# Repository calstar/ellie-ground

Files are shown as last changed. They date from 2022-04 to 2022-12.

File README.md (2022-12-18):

# ellie-ground
2022 Eillie Hot-fire Electronics Control

## Summary
**DAQboard.ino** file commands the ESP32 that reads data from sensors and commands from the COM Board, and sends data in a package to the COM Board.

**COMBoard.ino** file commands the ESP32 that receives data in a package from the DAQ  Board, sends commands to the DAQ Board, and sends data to MATLAB for plotting and data-saving purposes through the serial port.

**liveplot.m** is a MATLAB file that can receive data from the COM Board, create live plots, and save the data.
  1. **Change the test file name according to the trial number in the liveplot.m file.**
  2. Click "Run" to start the code, and close the plotting window to stop the code. Test data will be automatically stored in a spreadsheet under a folder called "**Test_Data_yyyy-mm-dd**."

## ESP32 MAC Addresses
- DAQ Breadboard:{0x24, 0x62, 0xAB, 0xD2, 0x85, 0xDC}
- COM Breadboard:{0xC4, 0xDD, 0x57, 0x9E, 0x91, 0x6C};
- DAQ Protoboard:

## ESP32 Pinouts (Updated 4/6)
-DAQ Breadboard:

## Software requirement
**Ctrl click (Windows) or Cmd click the following links to open them in new tabs**
1. Arduino (https://www.arduino.cc/en/software)
2. MATLAB (https://software.berkeley.edu/matlab®)
    - To control the serial port, you need to install the [**Instrument Control Toolbox**](https://www.mathworks.com/products/instrument.html).
3. (optional) An external code editing software such as Atom (https://atom.io) or Visual Studio (https://visualstudio.microsoft.com/downloads/).
    - Arduino IDE and MATLAB are sufficient for all the coding
4. (recommended) GitHub Desktop (https://desktop.github.com). You can pull, push, and edit files with ease. **Step 3 required if you would like to download GitHub Desktop as the software requires an external editor.**

## How to update
### Using Github Desktop
1. Make sure you have access to this project
    - Check with you administrators
2. Go to the Github app, sign in, and click on the top left corner. You should see a pop-up window with an "Add" button. Select that button and choose "Clone repository."
3. Search in "Filter you repositories" using the keyword "ellie-ground." Select the correct repository and click "Clone."
    - If you want this cloned repository to be in a different folder, change the "Local Path."
4. After you have edited and saved the file in the local repository, GitHub Desktop will detect changes and prompt you to commit. Make sure to double check your changes before committing.
5. On the bottom left corner, put down a short summary that describes what you have changed, then click "Commit to **main**."
6. In the middle of the screen (or on the top banner) you will see "Push commits to the origin remote." If you are sure that the commit is ready, click "Push origin."
6. Check the project online and see if the changes have been reflected.

### Using Git
Please refer to https://rocketry.gitbook.io/public/tutorials/avionics/git-and-workflow for more information.

## Helpful resources
### ESP32-DevkitC (for PCB application - antenna sticks out of board)
Getting started

https://docs.espressif.com/projects/esp-idf/en/latest/esp32/hw-reference/esp32/get-started-devkitc.html

Pinout reference

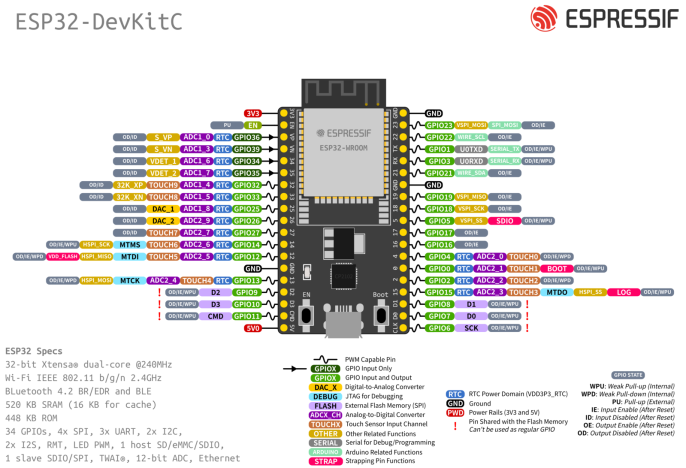
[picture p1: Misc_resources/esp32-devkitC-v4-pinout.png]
esp32 devkitC pinout ESP32 DevkitC Pinout


### ESP32-WROOM (for breadboard/protoboard application - antenna does NOT stick out of board)

Pinout reference
esp32 wroom pinout

### ESP32-HUZZAH (for breadboard/protoboard application)

Pinout reference
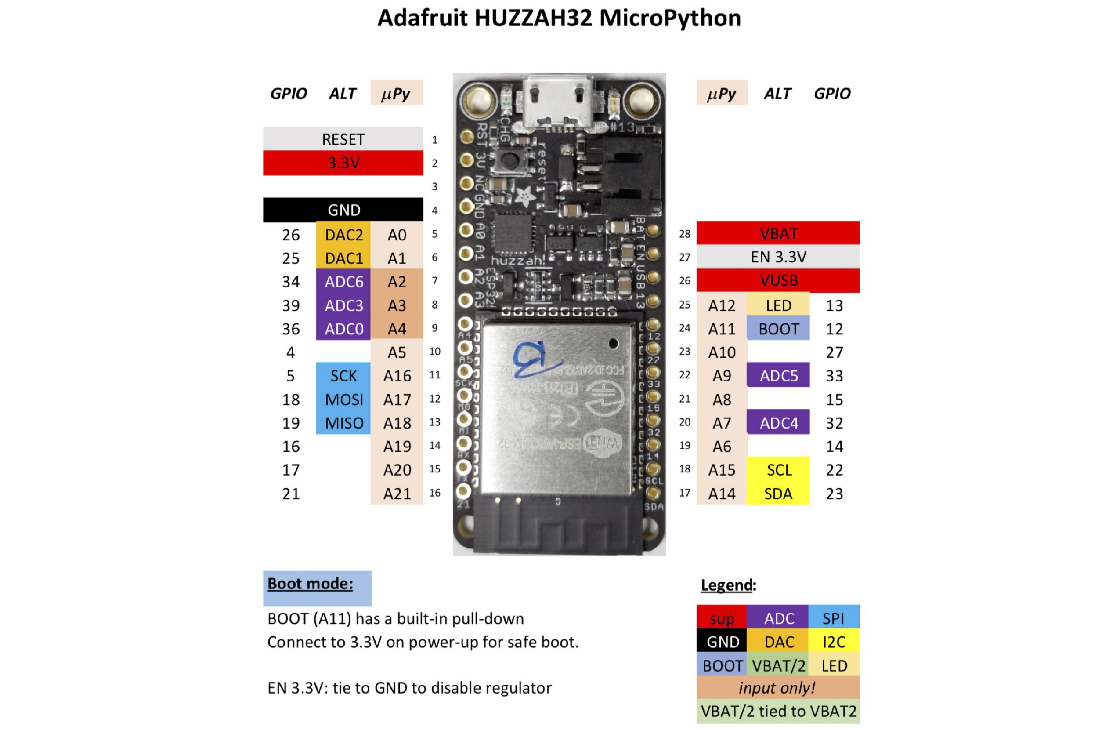
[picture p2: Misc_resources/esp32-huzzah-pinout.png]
esp32 devkitC pinout ESP32 HUZZAH Pinout


### Pressure transducer color code
Red - E+

Black - E-

Green - A-

White - A+

Other possible combinations: Blue E+; Red E-; Green A-; Black A+

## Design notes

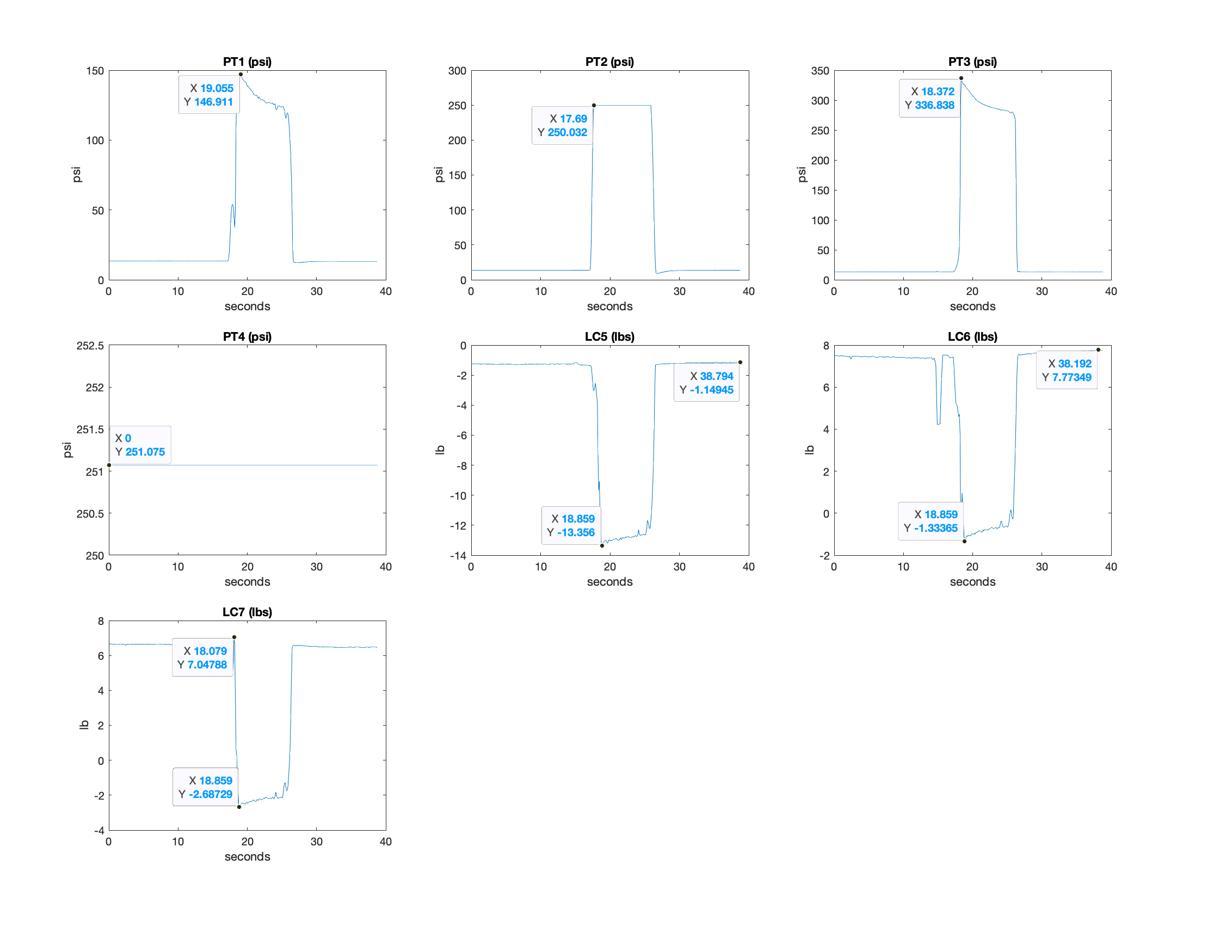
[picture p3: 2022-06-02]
DataAnalysis/Hotfire2DataTrimmedGraph.png

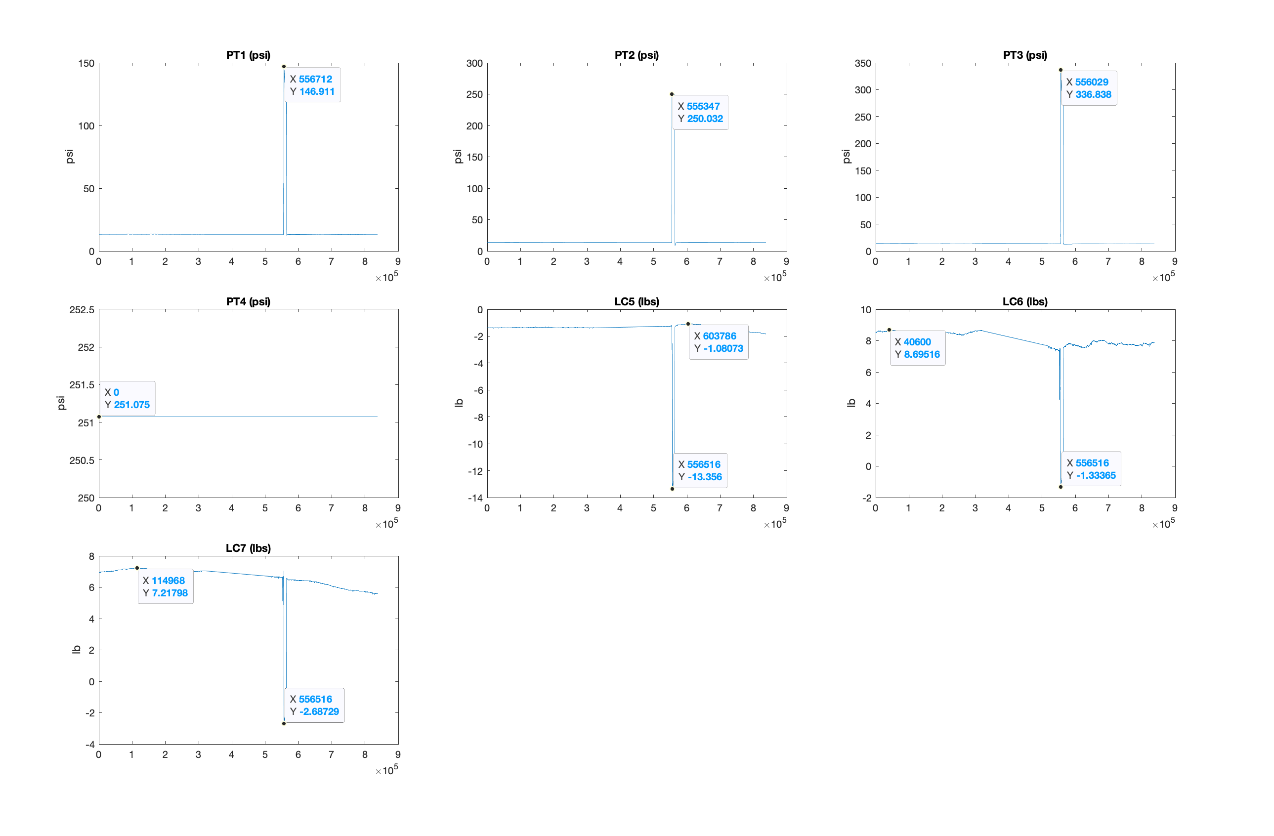
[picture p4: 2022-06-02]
DataAnalysis/Hotfire2DataProcessed.png

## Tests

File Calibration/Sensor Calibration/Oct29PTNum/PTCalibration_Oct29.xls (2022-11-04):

PT 1 | PT 2 | PT 3 | PT 4 | PT 5 | PT 6 | PT 7 | PT Readings
0.0009706526828 | 12.51203827 | 0.0009893543334 | 0.2012704162 | -133719235369059248 | -36146633045445000 | 69354593096977224
1.65048153 | -23513.65328 | 31.48686305 | 1559.537684 | -20057885305358816 | 30001705427719392 | -113741532679042560
8380.388889 | 1885.814815 | -22136.64815 | -7710.796296 | -0.15 | 0.83 | 1.64 | 14.7
55554.43046 | 1883.064982 | 24805.82 | -7349.636364 | -0.15 | 0.83 | 1.64 | 50
118709.5503 | 1885.245989 | 86323.95266 | -7282.704301 | -0.15 | 0.83 | 1.64 | 115
80205.55208 | 1884.510417 | 48400.64583 | -7229.824176 | -0.15 | 0.83 | 1.64 | 77
137342.2368 | 1889.48125 | 104446.4649 | -7198.40625 | -0.15 | 0.83 | 1.64 | 140

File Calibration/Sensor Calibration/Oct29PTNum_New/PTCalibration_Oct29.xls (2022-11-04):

PT 1 | PT 2 | PT 3 | PT 4 | PT 5 | PT 6 | PT 7 | PT Readings
0.0009157457122 | 0.03437664856 | 0.00104545149 | -0.007990707251 | 118398310289181120 | -17172367727786096 | 19827824667406704
7.487624458 | 14.54881995 | 26.42813521 | 19.595128 | 17759746543377252 | 14253065214062518 | -32517632454546908
8380.388889 | 1885.814815 | -22136.64815 | -7710.796296 | -0.15 | 0.83 | 1.64 | 14.7
55554.43046 | 1883.064982 | 24805.82 | -7349.636364 | -0.15 | 0.83 | 1.64 | 50
118709.5503 | 1885.245989 | 86323.95266 | -7282.704301 | -0.15 | 0.83 | 1.64 | 115
80205.55208 | 1884.510417 | 48400.64583 | -7229.824176 | -0.15 | 0.83 | 1.64 | 77
137342.2368 | 1889.48125 | 104446.4649 | -7198.40625 | -0.15 | 0.83 | 1.64 | 140
0 | 0 | -1 | 0 | -0.15 | 0.83 | 1.64 | 14.7

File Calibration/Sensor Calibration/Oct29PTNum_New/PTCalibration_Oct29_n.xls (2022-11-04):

PT 1 | PT 2 | PT 3 | PT 4 | PT 5 | PT 6 | PT 7 | PT Readings
0 | 0 | -153515758976703840 | 0 | 1.861742316e+15 | -3.535751283e+14 | -4.561532801e+14
19.85 | 19.85 | -153515758976703840 | 19.85 | 2.792613475e+14 | 2.934673565e+14 | 7.480913793e+14
0 | 0 | -1 | 0 | -0.15 | 0.83 | 1.64 | 14.7
0 | 0 | -1 | 0 | -0.15 | 0.83 | 1.64 | 25

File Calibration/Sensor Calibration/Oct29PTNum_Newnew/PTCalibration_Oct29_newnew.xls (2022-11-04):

PT 1 | PT 2 | PT 3 | PT 4 | PT 5 | PT 6 | PT 7 | PT Readings
0 | -234.3810036 | 0.1022941834 | 0 | -27526872320401832 | 4.169703457e+15 | 2.484431584e+15
111.51 | 105.7888889 | 28.23953968 | 111.51 | -4129030848060160 | -3460853869241820 | -4074467797335228
0 | 0 | 255 | 0 | -0.15 | 0.83 | 1.64 | -15.9
0 | 0 | 511 | 0 | -0.15 | 0.83 | 1.64 | 77
0 | 0 | 511 | 0 | -0.15 | 0.83 | 1.64 | 121
0 | -0.2440944882 | 1023 | 0 | -0.15 | 0.83 | 1.64 | 163
0 | 0 | 725.2927864 | 0 | -0.15 | 0.83 | 1.64 | 220
0 | 0 | 1023 | 0 | -0.15 | 0.83 | 1.64 | 195
0 | 0 | 1023 | 0 | -0.15 | 0.83 | 1.64 | 190
0 | 0 | 1023 | 0 | -0.15 | 0.83 | 1.64 | 63
0 | 0 | 1023 | 0 | -0.15 | 0.83 | 1.64 | 54
0 | 0 | 1023 | 0 | -0.15 | 0.83 | 1.64 | 48

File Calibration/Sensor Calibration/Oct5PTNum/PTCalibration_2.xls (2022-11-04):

PT 1 | PT 2 | PT 3 | PT 4 | PT 5 | PT 6 | PT 7 | PT Readings
0 | 9.928154529e-07 | 0 | 0 | -1.000799917e+15 | 1.087005989e+14 | -9.153657779e+13
14.7125 | 14.81074651 | 14.7125 | 14.7125 | -1.501199876e+14 | -9.022149707e+13 | 1.501199876e+14
0 | -99582.5 | 0 | 0 | -0.15 | 0.83 | 1.64 | 14.7
0 | -90180.9589 | 0 | 0 | -0.15 | 0.83 | 1.64 | 14.7
0 | -116377.3364 | 0 | 0 | -0.15 | 0.83 | 1.64 | 14.7
0 | -89689.1 | 0 | 0 | -0.15 | 0.83 | 1.64 | 14.75

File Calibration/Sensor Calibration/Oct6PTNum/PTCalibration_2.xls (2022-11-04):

PT 1 | PT 2 | PT 3 | PT 4 | PT 5 | PT 6 | PT 7 | PT Readings
0 | -7.311162168e-08 | 0 | 0 | 1.772839064e+14 | -2.232511728e+12 | -1.848005434e+13
14.70833333 | 14.70432553 | 14.70833333 | 14.70833333 | 2.659258596e+13 | 1.852984734e+12 | 3.030728911e+13
0 | -99582.5 | 0 | 0 | -0.15 | 0.83 | 1.64 | 14.7
0 | -90180.9589 | 0 | 0 | -0.15 | 0.83 | 1.64 | 14.7
0 | -116377.3364 | 0 | 0 | -0.15 | 0.83 | 1.64 | 14.7
0 | -89689.1 | 0 | 0 | -0.15 | 0.83 | 1.64 | 14.75
0 | 34295.94872 | 0 | 0 | -0.15 | 0.83 | 1.64 | 14.7
0 | 32628.66667 | 0 | 0 | -0.15 | 0.83 | 1.64 | 14.7

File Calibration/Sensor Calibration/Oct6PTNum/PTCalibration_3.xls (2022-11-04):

PT 1 | PT 2 | PT 3 | PT 4 | PT 5 | PT 6 | PT 7 | PT Readings
0 | 2.427443259e-05 | 18.31428571 | 0 | -308703343514374528 | -61703265420964744 | 50848568963502208
79.74444444 | 15.88315189 | 83.81428571 | 79.74444444 | -46305501527156112 | 51213710299400792 | -83391653100143536
0 | 26169.49153 | 0 | 0 | -0.15 | 0.83 | 1.64 | 14.7
0 | 946688.05 | 0 | 0 | -0.15 | 0.83 | 1.64 | 43
0 | 2184658.889 | -1 | 0 | -0.15 | 0.83 | 1.64 | 51
0 | 2312099.571 | 0 | 0 | -0.15 | 0.83 | 1.64 | 80
0 | 3136231.319 | 0 | 0 | -0.15 | 0.83 | 1.64 | 102
0 | 3182059.057 | 0 | 0 | -0.15 | 0.83 | 1.64 | 97
0 | 3586923.865 | 0 | 0 | -0.15 | 0.83 | 1.64 | 116
0 | 4287929.869 | 0 | 0 | -0.15 | 0.83 | 1.64 | 134

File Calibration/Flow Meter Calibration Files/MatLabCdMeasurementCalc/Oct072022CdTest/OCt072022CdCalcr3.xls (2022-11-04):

Time(ms) | PT 2 | PT 3 | PT 4 | volume flow (m^3/s) | break Interval | mass flow (kg/s) | Cd Value | Reynolds Num
114031 | 6894.76 | 101352.93 | 1 | 0 | 3000 | 0 | 0 | 0
117031 | 6894.76 | 101352.93 | 1 | 0 | 3000 | 0 | 0 | 0
120031 | 6894.76 | 101352.93 | 1 | 0 | 3000 | 0 | 0 | 0
123032 | 6894.76 | 101352.93 | 1 | 0 | 3001 | 0 | 0 | 0
126032 | 6894.76 | 101352.93 | 1 | 0 | 3000 | 0 | 0 | 0
128879 | 6894.76 | 101352.93 | 1 | 0 | 2847 | 0 | 0 | 0
128942 | 6894.76 | 101352.93 | 1 | 0 | 63 | 0 | 0 | 0
128980 | 6894.76 | 101352.93 | 1 | 0 | 38 | 0 | 0 | 0
129010 | 6894.76 | 101352.93 | 1 | 0 | 30 | 0 | 0 | 0
129035 | 6894.76 | 101352.93 | 1 | 0 | 25 | 0 | 0 | 0
129057 | 6894.76 | 101352.93 | 1 | 0 | 22 | 0 | 0 | 0
129077 | 6894.76 | 101352.93 | 1 | 0 | 20 | 0 | 0 | 0
129096 | 6894.76 | 101352.93 | 1 | 0 | 19 | 0 | 0 | 0
129114 | 6894.76 | 101352.93 | 1 | 0 | 18 | 0 | 0 | 0
129130 | 6894.76 | 101352.93 | 1 | 0 | 16 | 0 | 0 | 0
129146 | 6894.76 | 101352.93 | 1 | 0 | 16 | 0 | 0 | 0
129161 | 6894.76 | 101352.93 | 1 | 0 | 15 | 0 | 0 | 0
129175 | 6894.76 | 101352.93 | 1 | 0 | 14 | 0 | 0 | 0
129189 | 6894.76 | 101352.93 | 1 | 0 | 14 | 0 | 0 | 0
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

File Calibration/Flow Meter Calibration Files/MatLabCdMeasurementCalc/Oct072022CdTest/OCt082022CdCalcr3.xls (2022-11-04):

Time(ms) | PT 2 | PT 3 | PT 4 | volume flow (m^3/s) | break Interval | mass flow (kg/s) | Cd Value | Reynolds Num
36027 | 6894.76 | 101352.93 | 1 | 0 | 3001 | 0 | 0 | 0
39027 | 6894.76 | 101352.93 | 1 | 0 | 3000 | 0 | 0 | 0
42027 | 6894.76 | 101352.93 | 1 | 0 | 3000 | 0 | 0 | 0
44575 | 6894.76 | 101352.93 | 1 | 0 | 2548 | 0 | 0 | 0
44668 | 6894.76 | 101352.93 | 1 | 0 | 93 | 0 | 0 | 0
44719 | 6894.76 | 101352.93 | 1 | 0 | 51 | 0 | 0 | 0
44758 | 6894.76 | 101352.93 | 1 | 0 | 39 | 0 | 0 | 0
44791 | 6894.76 | 101352.93 | 1 | 0 | 33 | 0 | 0 | 0
44821 | 6894.76 | 101352.93 | 1 | 0 | 30 | 0 | 0 | 0
44847 | 6894.76 | 101352.93 | 1 | 0 | 26 | 0 | 0 | 0
44872 | 6894.76 | 101352.93 | 1 | 0 | 25 | 0 | 0 | 0
44896 | 6894.76 | 101352.93 | 1 | 0 | 24 | 0 | 0 | 0
44919 | 6894.76 | 101352.93 | 1 | 0 | 23 | 0 | 0 | 0
44941 | 6894.76 | 101352.93 | 1 | 0 | 22 | 0 | 0 | 0
44962 | 6894.76 | 101352.93 | 1 | 0 | 21 | 0 | 0 | 0
44983 | 6894.76 | 101352.93 | 1 | 0 | 21 | 0 | 0 | 0
45004 | 6894.76 | 101352.93 | 1 | 0 | 21 | 0 | 0 | 0
45024 | 6894.76 | 101352.93 | 1 | 0 | 20 | 0 | 0 | 0
45045 | 6894.76 | 101352.93 | 1 | 0 | 21 | 0 | 0 | 0
45065 | 6894.76 | 101352.93 | 1 | 0 | 20 | 0 | 0 | 0
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

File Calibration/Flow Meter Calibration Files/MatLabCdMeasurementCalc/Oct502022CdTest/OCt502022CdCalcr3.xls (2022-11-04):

Time(ms) | PT 2 | PT 3 | PT 4 | volume flow (m^3/s) | break Interval | mass flow (kg/s) | Cd Value | Reynolds Num
349916 | 137895.15 | 101352.93 | 0 | 0.0001133076307 | 96 | 0.000143900691 | 0.02778431128 | 5.316038151e-09
350004 | 137895.15 | 101352.93 | 0 | 0.0001122371665 | 88 | 0.0001425412014 | 0.02752182135 | 5.26581533e-09
350088 | 137895.15 | 101352.93 | 0 | 0.0001259108324 | 84 | 0.0001599067572 | 0.03087475873 | 5.90734079e-09
350179 | 137895.15 | 101352.93 | 0 | 0.000135928762 | 91 | 0.0001726295277 | 0.03333126825 | 6.37735058e-09
350272 | 137895.15 | 101352.93 | 0 | 0.0001290414354 | 93 | 0.000163882623 | 0.03164241796 | 6.054218849e-09
350365 | 137895.15 | 101352.93 | 0 | 9.777580043e-05 | 93 | 0.0001241752665 | 0.023975731 | 4.587333456e-09
350550 | 137895.15 | 101352.93 | 0 | 3.924362327e-05 | 185 | 4.983940155e-05 | 0.009622979823 | 1.841187545e-09
352600 | 137895.15 | 101352.93 | 0 | 0 | 2050 | 0 | 0 | 0

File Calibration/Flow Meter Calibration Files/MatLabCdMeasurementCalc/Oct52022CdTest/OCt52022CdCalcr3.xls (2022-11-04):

Time(ms) | PT 2 | PT 3 | PT 4 | volume flow (m^3/s) | break Interval | mass flow (kg/s) | Cd Value | Reynolds Num
616385 | 137895.15 | 101352.93 | 0 | 4.386883671e-05 | 394 | 5.571342263e-05 | 0.01075713442 | 2.058188033e-09
616461 | 137895.15 | 101352.93 | 0 | 0.0002053069637 | 76 | 0.0002607398439 | 0.05034358719 | 9.632357897e-09
616528 | 137895.15 | 101352.93 | 0 | 0.0003080311366 | 67 | 0.0003911995435 | 0.07553271502 | 1.445185345e-08
616616 | 137895.15 | 101352.93 | 0 | 0.0001200939701 | 88 | 0.000152519342 | 0.02944839837 | 5.634431879e-09
616725 | 137895.15 | 101352.93 | 0 | 8.486963714e-05 | 109 | 0.0001077844392 | 0.02081099394 | 3.981816811e-09
616860 | 137895.15 | 101352.93 | 0 | 5.033201708e-05 | 135 | 6.392166169e-05 | 0.01234197927 | 2.361420155e-09
617980 | 137895.15 | 101352.93 | 0 | 3.445683031e-05 | 1120 | 4.376017449e-05 | 0.008449204106 | 1.616606254e-09

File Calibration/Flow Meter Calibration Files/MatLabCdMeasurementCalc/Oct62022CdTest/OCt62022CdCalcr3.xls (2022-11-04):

Time(ms) | PT 2 | PT 3 | PT 4 | volume flow (m^3/s) | break Interval | mass flow (kg/s) | Cd Value | Reynolds Num
517058 | 103421.36 | 101352.93 | 0 | 0 | 82008 | 0 | 0 | 0
520059 | 103421.36 | 101352.93 | 0 | 0 | 3001 | 0 | 0 | 0
523059 | 103421.36 | 101352.93 | 0 | 0 | 3000 | 0 | 0 | 0
526059 | 103421.36 | 101352.93 | 0 | 0 | 3000 | 0 | 0 | 0
529059 | 103421.36 | 101352.93 | 0 | 0 | 3000 | 0 | 0 | 0
529351 | 103421.36 | 101352.93 | 0 | 0 | 292 | 0 | 0 | 0
529422 | 103421.36 | 101352.93 | 0 | 0 | 71 | 0 | 0 | 0
529476 | 103421.36 | 101352.93 | 0 | 0 | 54 | 0 | 0 | 0
529543 | 103421.36 | 101352.93 | 0 | 0 | 67 | 0 | 0 | 0
529613 | 103421.36 | 101352.93 | 0 | 0 | 70 | 0 | 0 | 0
529675 | 103421.36 | 101352.93 | 0 | 0 | 62 | 0 | 0 | 0
529736 | 103421.36 | 101352.93 | 0 | 0 | 61 | 0 | 0 | 0
529798 | 103421.36 | 101352.93 | 0 | 0 | 62 | 0 | 0 | 0
529862 | 103421.36 | 101352.93 | 0 | 0 | 64 | 0 | 0 | 0
529928 | 103421.36 | 101352.93 | 0 | 0 | 66 | 0 | 0 | 0
529994 | 103421.36 | 101352.93 | 0 | 0 | 66 | 0 | 0 | 0
530065 | 103421.36 | 101352.93 | 0 | 0 | 71 | 0 | 0 | 0
530149 | 103421.36 | 101352.93 | 0 | 0 | 84 | 0 | 0 | 0
530271 | 103421.36 | 101352.93 | 0 | 0 | 122 | 0 | 0 | 0
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

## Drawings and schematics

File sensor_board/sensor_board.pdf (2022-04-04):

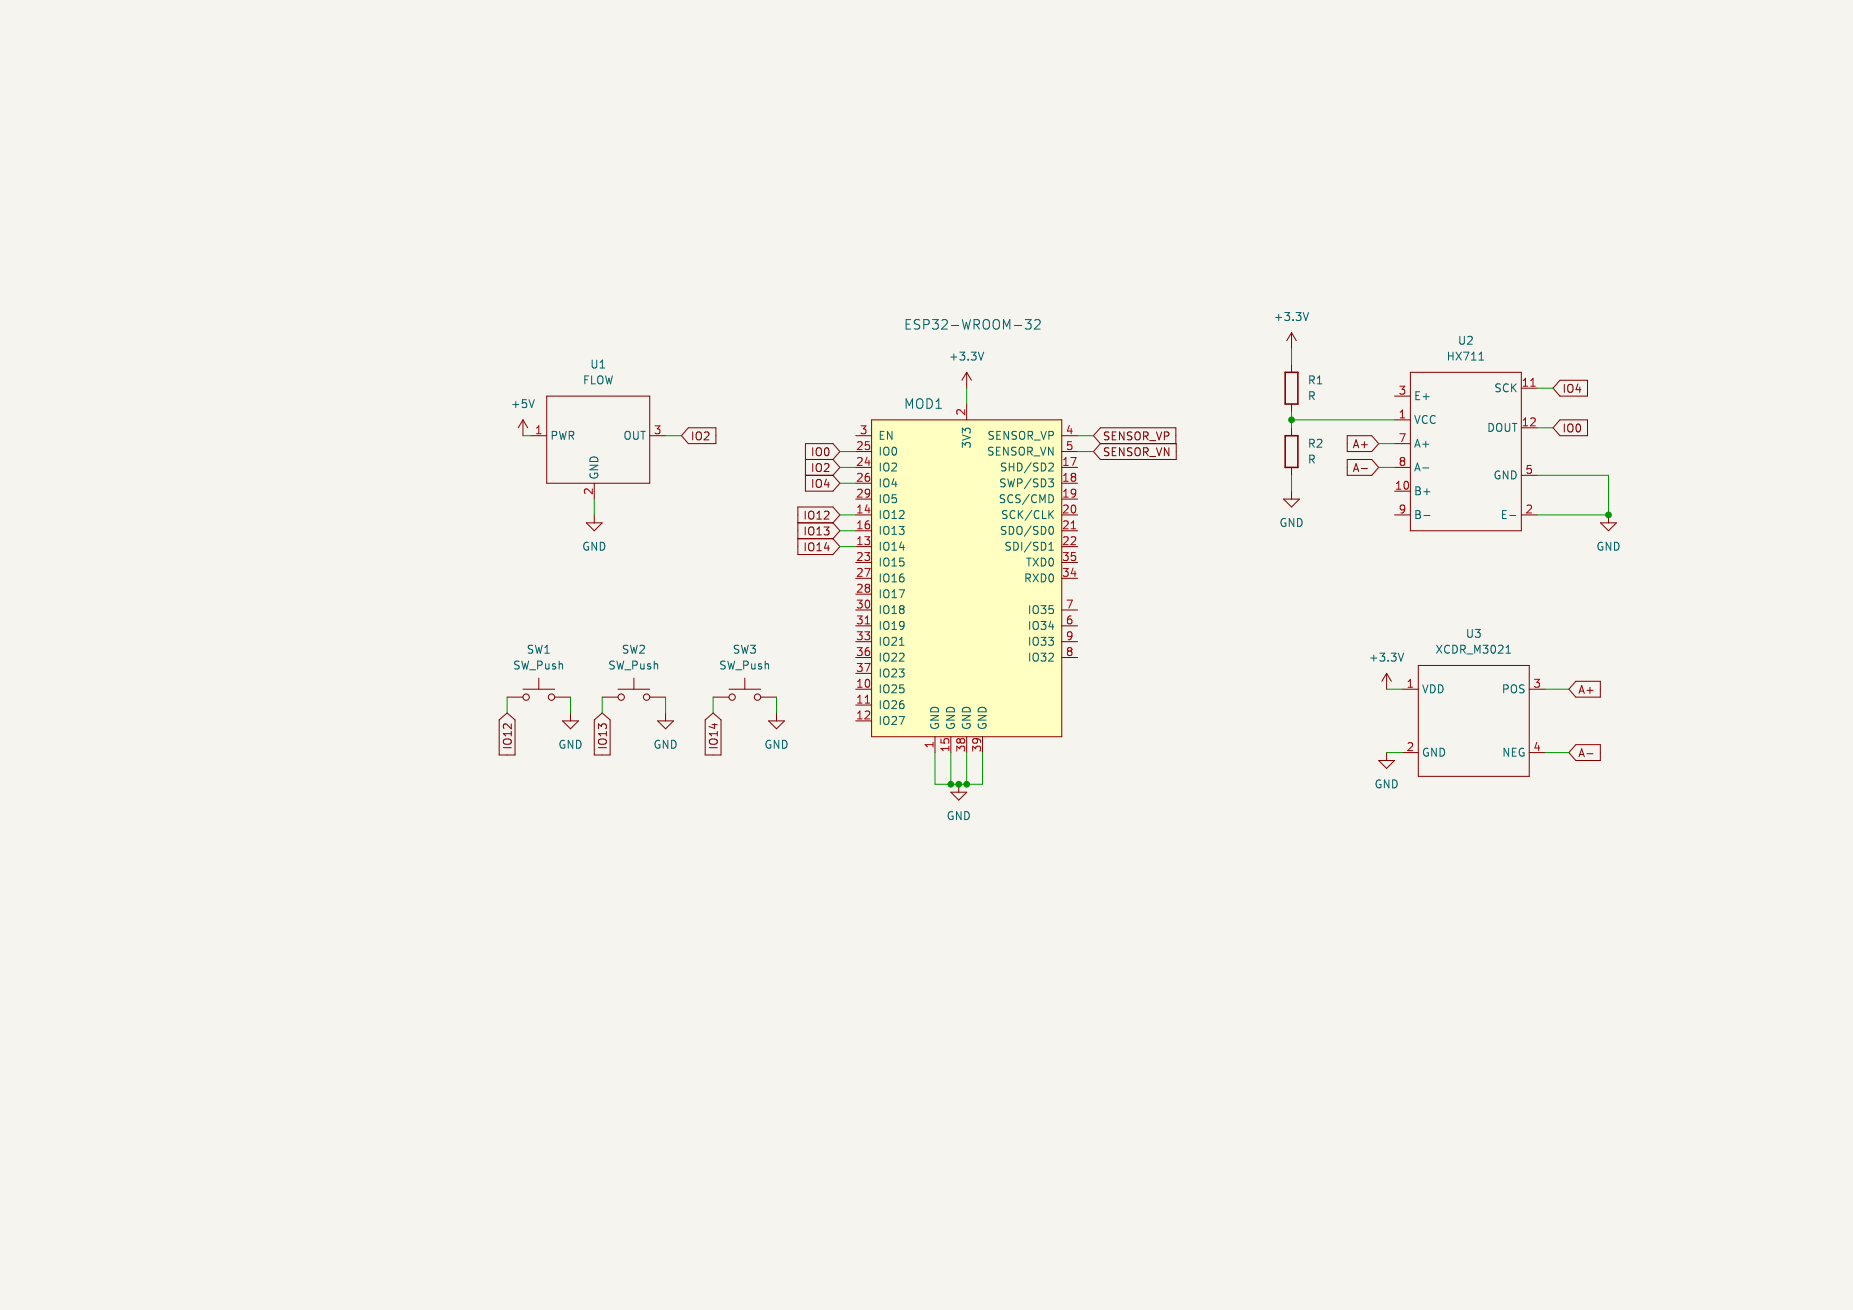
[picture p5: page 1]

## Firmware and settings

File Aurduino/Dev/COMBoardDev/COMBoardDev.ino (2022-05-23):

#include <esp_now.h>
#include <WiFi.h>
#include <ESP32Servo.h>
#include <Wire.h>
#include <Arduino.h>
#include "HX711.h"

#define BUTTON1 19
#define BUTTON2 17
#define BUTTON3 16
#define BUTTON4 21 //SET PIN NUMBER BUTTON

#define INDICATOR1  4 // state 2 light
#define INDICATOR2 23 // armed indicator
#define INDICATOR3 22//Servo1 indicator
#define INDICATOR4 14//seevo 2
#define INDICATOR5 25//daq indicaor
#define INDICATOR6 5//com indicator




#define servo1ClosedPosition 100
#define servo1OpenPosition 10
#define servo2ClosedPosition 80
#define servo2OpenPosition 160

float pressTime = 0;




String success;
String message;
int incomingMessageTime;
int servo1_curr = servo1ClosedPosition;
int servo2_curr = servo2ClosedPosition;
float incomingS1 = 0;
float incomingS2 = 0;
short int incomingPT1 = 4;
short int incomingPT2 = 4;
short int incomingPT3 = 4;
short int incomingPT4 = 4;
short int incomingFM = 0;
short int incomingLC1 = 0;
short int incomingLC2 = 0;
short int incomingLC3 = 0;
short int incomingI = 0;
int incomingDebug=0;
int actualState = -5;
short int queueSize=0;
esp_now_peer_info_t peerInfo;
bool pressed1 = false;
bool pressed2 = false;
bool pressed3 = false;
int commandstate = 0;


//TIMING VARIABLES
int state=-1;
int loopStartTime=0;
int ignitionSendDelay=50;
int pollingSendDelay=100;
int SendDelay=pollingSendDelay;

int commandedState;
int serialState;

int S1=servo1ClosedPosition;
int S2=servo2ClosedPosition;
int lastSendTime=0;

int lastPrintTime=0;
int PrintDelay =1000;



// SET FOR ACTIVE MODE //
bool hotfireMode = true;
//SET IF PLOTTING WITH MATLAB OR NOT. SERVO MANUAL CONTROL AND
//MATLAB PLOTTING ARE NOT COMPATIBLE DUE TO USING THE SAME SERIAL
//INPUT. IF TRUE, PLOTTING ENABLED. IF FALSE, MANUAL CONTROL ENABLED
bool MatlabPlot = true;


float button1Time = 0;
float currTime = 0;
float loopTime = 0;

float receiveTimeDAQ = 0;
float receiveTimeCOM = 0;

//for blinking LED during Data Collection
int x = 1;
unsigned long t1;
unsigned long t2;

//

//DAQ Breadboard {0x24, 0x62, 0xAB, 0xD2, 0x85, 0xDC}
//DAQ Protoboard {0x0C, 0xDC, 0x7E, 0xCB, 0x05, 0xC4}
//NON BUSTED DAQ {0x7C, 0x9E, 0xBD, 0xD8, 0xFC, 0x14}
// uint8_t broadcastAddress[] = {0x7C, 0x9E, 0xBD, 0xD8, 0xFC, 0x14}; //change to new Mac Address
// {0xC4, 0xDD, 0x57, 0x9E, 0x96, 0x34};

uint8_t broadcastAddress[] = {0x30, 0xC6, 0xF7, 0x2A, 0x28, 0x04};
//{0x30, 0xC6, 0xF7, 0x2A, 0x28, 0x04}

//Structure example to send data
//Must match the receiver structure
typedef struct struct_message {
    int messageTime;
    short int pt1;
    short int pt2;
    short int pt3;
    short int pt4;
    short int lc1;
    short int lc2;
    short int lc3;
    short int fm;
    unsigned char S1;
    unsigned char S2;
        int commandedState = 0;
        int DAQstate=0;

    unsigned char I;
    short int queueSize;
    int Debug;
} struct_message;

// Create a struct_message called Readings to recieve sensor readings remotely
struct_message incomingReadings;

// Create a struct_message to send commands
struct_message Commands;

//


void OnDataSent(const uint8_t *mac_addr, esp_now_send_status_t status) {
 // Serial.print("\r\nLast Packet Send Status:\t");
 // Serial.println(status == ESP_NOW_SEND_SUCCESS ? "Delivery Success" : "Delivery Fail");

  if (status == 0){
    success = "Delivery Success :)";
    digitalWrite(INDICATOR2, HIGH);
    receiveTimeDAQ = millis();
  }
  else{
    success = "Delivery Fail :(";
    digitalWrite(INDICATOR2, LOW);
  }
  // Serial.print(Commands.S1);
  // Serial.print(" ");
  // Serial.println(Commands.S2);

}

void OnDataRecv(const uint8_t * mac, const uint8_t *incomingData, int len) {
  memcpy(&incomingReadings, incomingData, sizeof(incomingReadings));
 // Serial.print("Bytes received: ");
   // Serial.println(len);
  incomingPT1 = incomingReadings.pt1;
     // Serial.print(incomingPT1);

     digitalWrite(INDICATOR1,HIGH);

  incomingMessageTime= incomingReadings.messageTime;
  incomingPT2 = incomingReadings.pt2;
  incomingPT3 = incomingReadings.pt3;
  incomingPT4 = incomingReadings.pt4;
  incomingFM = incomingReadings.fm;
  incomingLC1 = incomingReadings.lc1;
  incomingLC2 = incomingReadings.lc2;
  incomingLC3 = incomingReadings.lc3;
  incomingS1 = incomingReadings.S1;
  incomingS2 = incomingReadings.S2;
  queueSize= incomingReadings.queueSize;
  incomingI = incomingReadings.I;
  actualState = incomingReadings.DAQstate;
  incomingDebug= incomingReadings.Debug;


  receiveTimeCOM = millis();
  // Serial.println("Data received");
  RecieveDataPrint();

}

void SerialRead() {
    if (Serial.available() > 0) {
 serialState=Serial.read()-48;
 Serial.print("AVAILABLE--------------------");
   // Serial.println(serialState);
   // Serial.println(" ");

  }
     //   Serial.println(commandedState);
     //    Serial.println(" ");

}









void setup() {
  Serial.println("Start of Setup");
  Commands.S1 = servo1ClosedPosition;
  Commands.S2 = servo2ClosedPosition;
  // put your setup code here, to run once:
  Serial.begin(115200);
  pinMode(BUTTON1,INPUT);
  pinMode(BUTTON2, INPUT);
  pinMode(BUTTON3,INPUT);
  pinMode(BUTTON4, INPUT);

  pinMode(INDICATOR2, OUTPUT);
  pinMode(INDICATOR3, OUTPUT);
  pinMode(INDICATOR4, OUTPUT);
  pinMode(INDICATOR5, OUTPUT);
  pinMode(INDICATOR6, OUTPUT);
  pinMode(INDICATOR1, OUTPUT);

  digitalWrite(INDICATOR2,LOW);
  digitalWrite(INDICATOR3, LOW);
  digitalWrite(INDICATOR4, LOW);
  digitalWrite(INDICATOR5, LOW);
  digitalWrite(INDICATOR6, LOW);
  digitalWrite(INDICATOR1, LOW);


  //set device as WiFi station
  WiFi.mode(WIFI_STA);

  //initialize ESP32
   if (esp_now_init() != ESP_OK) {
  //  Serial.println("Error initializing ESP-NOW");
    return;
  }
   // Once ESPNow is successfully Init, we will register for Send CB to
  // get the status of Trasnmitted packet
  esp_now_register_send_cb(OnDataSent);

  // Register peer
  memcpy(peerInfo.peer_addr, broadcastAddress, 6);
  peerInfo.channel = 0;
  peerInfo.encrypt = false;

  // Add peer
  if (esp_now_add_peer(&peerInfo) != ESP_OK){
 //   Serial.println("Failed to add peer");
    return;
  }
  // Register for a callback function that will be called when data is received
  esp_now_register_recv_cb(OnDataRecv);

  //  Serial.println(WiFi.macAddress());


}



void printLine(String string) {
  Serial.println(string);
}


void LEDUpdate() {


if (incomingS1 == servo1OpenPosition) digitalWrite(INDICATOR3,HIGH); else digitalWrite(INDICATOR3,LOW);
if (incomingS2 == servo2OpenPosition) digitalWrite(INDICATOR4,HIGH); else digitalWrite(INDICATOR4,LOW);
digitalWrite(INDICATOR1,LOW);


}



void loop() {
loopStartTime=millis();
SerialRead();
// State selector
//Serial.println(actualState);

LEDUpdate();


switch (state) {

  case (17): //BASIC WIFI TEST DEBUG STATE A STATE
   wifiDebug();

    if (serialState==1) {state=1;}
  break;


  case (18): //COM INTERFACE BUTTON DEBUG STATE  B STATE
  comDebug();

    if (serialState==1) {state=1;}
  break;

  case (-1): //start single loop

  state=0;
  break;


  case (0): //Default/idle
      idle();


    state=1;
    break;

  case (1): //Polling
      polling();



      if ((digitalRead(BUTTON2)==1)||(serialState==2)) { state=3; S1=servo1ClosedPosition; S2=servo2ClosedPosition; SendDelay=pollingSendDelay; }
    if (serialState==18) {state=18;}
    if (serialState==17) {state=17;}

    break;

  case (2): //Manual Servo Control

 manualControl();


   if ((serialState==40)) { state=0; SendDelay=pollingSendDelay; }

    break;

  case (3): //Armed

armed();


    //button to ignition
      if ((digitalRead(BUTTON3)==1)||(serialState==3)) { state=4; S1=servo1ClosedPosition; S2=servo2ClosedPosition; SendDelay=ignitionSendDelay; }
      //RETURN BUTTON
      if ((digitalRead(BUTTON1)==1)||(serialState==1)) { state=1; S1=servo1ClosedPosition; S2=servo2ClosedPosition; SendDelay=pollingSendDelay; }

    break;


  case (4): //Ignition

    ignition();
    //HOTFIRE BUTTON
      if ((digitalRead(BUTTON4)==1)||(serialState==4)) state=5;
      //RETURN BUTTON
      if ((digitalRead(BUTTON1)==1)||(serialState==1)) { state=1; S1=servo1ClosedPosition; S2=servo2ClosedPosition; SendDelay=pollingSendDelay; }



    break;
  case (5): //Hotfire stage 1

    hotfire();

    if (actualState==0) state=0;


    break;

}

}
void statePrint() {


}



void idle() {
  dataSendCheck();
    digitalWrite(INDICATOR5,LOW);

}

void polling() {
  commandedState=1;
  dataSendCheck();
  digitalWrite(INDICATOR5,HIGH);

}

void manualControl() {
  commandedState=2;
  dataSendCheck();

    digitalWrite(INDICATOR5,LOW);


}

void armed() {
  commandedState=3;
  dataSendCheck();
  digitalWrite(INDICATOR5,LOW);

}

void ignition() {
  commandedState=4;
  dataSendCheck();

}

void hotfire() {
  commandedState=5;
  dataSendCheck();

}

void dataSendCheck() {
  if ((loopStartTime-lastSendTime) > SendDelay) dataSend();
}


void dataSend() {
   // Set values to send
  Commands.S1= S1;
  Commands.S2= S2;
  Commands.commandedState = commandedState;

  // Send message via ESP-NOW
  esp_err_t result = esp_now_send(broadcastAddress, (uint8_t *) &Commands, sizeof(Commands));

  if (result == ESP_OK) {
   //  Serial.println("Sent with success Data Send");
  }
  else {
  //   Serial.println("Error sending the data");
  }

  lastSendTime=loopStartTime;
}







void oldcode() {
  message = "";





  switch (state) {
    case 0:


      digitalWrite(INDICATOR2, LOW);
      digitalWrite(INDICATOR1, LOW);

      currTime = millis();
      if (pressed1 && ((currTime - button1Time) > 1000)) {
        state = 1;
        button1Time = currTime;
        // Serial.println("State 1");
        // Serial.println("BUTTON 1 GOOD");
      }

      break;

    case 1:


      pressed2 = digitalRead(BUTTON2);
      pressed3 = digitalRead(BUTTON1);
      currTime = millis();
      if (pressed2) {

        if (hotfire) state = 4; else state = 2;

        if (hotfire) {
          state = 4;
        } else {
          state = 2;
      }

        // Serial.println("State 2");
      }
      if (pressed3 && ((currTime - button1Time) > 1000)) {
        button1Time = currTime;
        state = 0;
        // Serial.println("State 0");
      }
      if ((millis() - receiveTimeDAQ) > 50) {
        digitalWrite(INDICATOR5, LOW);
      }
      if ((millis() - receiveTimeCOM) > 50) {
        digitalWrite(INDICATOR6, LOW);
      }
      break;
    case 2:
    //  Serial.println("State 2");
      //Serial.println("IN CASE 2");
      if (MatlabPlot) {
        Commands.S1 = 90 - servo1_curr;
        Commands.S2 = 90 - servo2_curr;
        servo1_curr = 90 - servo1_curr;
        servo2_curr = 90 - servo2_curr;
        pressTime = millis();
        digitalWrite(INDICATOR1, HIGH);

        while (millis() - pressTime <= 5000) {

          t2=millis();
          if (t2-t1 >=100){
              x=1-x;
              t1=millis();
              digitalWrite(INDICATOR2,x);
              // Serial.print(t1);
            }

          pressed3 = digitalRead(BUTTON1);
          if (pressed3) {
            state = 0;
            break;
          }
          if (state == 3) {
            break;
          }
          if ((millis() - receiveTimeDAQ) > 50) {
            digitalWrite(INDICATOR5, LOW);
          }
          if ((millis() - receiveTimeCOM) > 50) {
            digitalWrite(INDICATOR6, LOW);
          }

          if ((millis() - loopTime) >= 50) {
            esp_err_t result = esp_now_send(broadcastAddress, (uint8_t *) &Commands, sizeof(Commands));
            if (result != ESP_OK) {
              break;
            // Serial.println("Sent with success");
            }
            //else {
              //Serial.println("Error sending the data");



         }
        }

      } else {
        while (!Serial.available()) {
          pressed3 = digitalRead(BUTTON1);
          // Serial.print(pressed3);
          delay(5);
          if ((millis() - receiveTimeDAQ) > 50) {
            digitalWrite(INDICATOR5, LOW);
          }
          if ((millis() - receiveTimeCOM) > 50) {
            digitalWrite(INDICATOR6, LOW);
          }
          esp_err_t result = esp_now_send(broadcastAddress, (uint8_t *) &Commands, sizeof(Commands));
            if (result != ESP_OK) {
              break;
            // Serial.println("Sent with success");
            }
            //else {
              //Serial.println("Error sending the data");
            //}
          if (pressed3) {
            state = 0;
            // Serial.println("State 0");
            break;}  //waiting for inputs
          }
        String angles = Serial.readString();
        int index = angles.indexOf(",");
        String readAngle1 = angles.substring(0, index);
        String readAngle2 = angles.substring(index+1, angles.length());
        if (angles.length() >= 3) {
          Serial.println(readAngle1);
          Serial.println(readAngle2);
          Commands.S1 = readAngle1.toInt();
          Commands.S2 = readAngle2.toInt();
          if (Commands.S1 == servo1ClosedPosition) {
            digitalWrite(INDICATOR3, LOW);
          } else {
            digitalWrite(INDICATOR3, HIGH);
          }

          if (Commands.S2 == servo2ClosedPosition) {
            digitalWrite(INDICATOR4, LOW);
          } else {
            digitalWrite(INDICATOR4, HIGH);
          }
          esp_err_t result = esp_now_send(broadcastAddress, (uint8_t *) &Commands, sizeof(Commands));
          if (result != ESP_OK) {
              break;
            // Serial.println("Sent with success");
            }
            //else {
              //Serial.println("Error sending the data");
            //}

        }

      }
      break;
     case 3:
    //  Serial.println("State 3");
      Commands.S1 = servo1ClosedPosition;
      Commands.S2 = servo2ClosedPosition;
      digitalWrite(INDICATOR5, LOW);
      digitalWrite(INDICATOR6, LOW);
      digitalWrite(INDICATOR3, LOW);
      digitalWrite(INDICATOR4, LOW);
      if ((millis() - receiveTimeDAQ) > 50) {
        digitalWrite(INDICATOR5, LOW);
      }
      if ((millis() - receiveTimeCOM) > 50) {
        digitalWrite(INDICATOR6, LOW);
      }

      break;
    case 4:


      // Serial.println("State 4");
      if (incomingReadings.DAQstate == 4 || commandstate == 4){
        Commands.commandedState = 4;
        Serial.println("case 3 command state 3");


      } else {
          Commands.commandedState = 3;
          Serial.println("case 4 command state 3");
      }


      digitalWrite(INDICATOR1, HIGH);
      if (digitalRead(BUTTON1)) {
        state = 0;
        }
        if ((millis() - receiveTimeDAQ) > 100) {
          digitalWrite(INDICATOR5, LOW);
        }
      if ((millis() - receiveTimeCOM) > 100) {
        digitalWrite(INDICATOR6, LOW);
        }



      if (digitalRead(BUTTON1)) {
        state = 0;
      }
      if ((millis() - receiveTimeDAQ) > 100) {
        digitalWrite(INDICATOR5, LOW);
      }
      if ((millis() - receiveTimeCOM) > 100) {
        digitalWrite(INDICATOR6, LOW);
      }
      break;
    case 5:
    Serial.println(commandstate);
    if (incomingReadings.DAQstate == 5 || commandstate == 5) {
        Commands.commandedState = 5;

    } else  {
        Commands.commandedState = 4;
      }



      if (digitalRead(BUTTON4)) {
        Commands.commandedState = 5;
        commandstate = 5;
        Serial.print("yyyyyyy");

      if (digitalRead(BUTTON4)) {
        // Commands.I = true;
        Commands.S1 = servo1OpenPosition;
        Commands.S2 = servo2OpenPosition;
        // Serial.println(Commands.I);
        esp_err_t result = esp_now_send(broadcastAddress, (uint8_t *) &Commands, sizeof(Commands));

        if (result != ESP_OK) {

          break;
          }


        state = 0;

        float now = millis();
        float runningTime = millis();
        digitalWrite(INDICATOR3, HIGH);
        digitalWrite(INDICATOR4, HIGH);
        while ((now - runningTime) <= 3000) {
          now = millis();

        }
        digitalWrite(INDICATOR3, LOW);
        Commands.S1 = servo1ClosedPosition;

        now = millis();
        runningTime = millis();
        while ((now- runningTime) <= 500) {
          now = millis();


         // printLine(message);
          now = millis();
        }
        Commands.S2 = servo2ClosedPosition;

        digitalWrite(INDICATOR4, LOW);
      }
      if (digitalRead(BUTTON1)) {
        state = 0;
      }

    delay(30);
  }




  RecieveDataPrint();


}
}

void RecieveDataPrint() {

  message = "";
  message.concat(millis());
  message.concat(" ");
  message.concat(incomingPT1);
  message.concat(" ");
  message.concat(incomingPT2);
  message.concat(" ");
  message.concat(incomingPT3);
  message.concat(" ");
  message.concat(incomingPT4);
  message.concat(" ");
  message.concat(incomingLC1);
  message.concat(" ");
  message.concat(incomingLC2);
  message.concat(" ");
  message.concat(incomingLC3);
  message.concat(" ");
  message.concat(incomingFM);
  message.concat(" ");
  message.concat(incomingS1);
  message.concat(" ");
  message.concat(incomingS2);
  message.concat(" ");
  message.concat(Commands.commandedState);
  message.concat(" ");
  message.concat(Commands.DAQstate);
  message.concat(" ");
  message.concat(queueSize);

  printLine(message);
}


void wifiDebug() {
  Commands.Debug=-64;
  dataSend();
  commandedState=17;

  Serial.println(incomingReadings.Debug);

}



void comDebug() {
Serial.print("COM Interface Debug Mode");
int Push_button_state = digitalRead(BUTTON1);
int Push_button_state2 = digitalRead(BUTTON2);
int Push_button_state3 = digitalRead(BUTTON3);
int Push_button_state4 = digitalRead(BUTTON4);

// if condition checks if push button is pressed
// if pressed LED will turn on otherwise remain off

if ( Push_button_state == HIGH )
{
  Serial.println("button1");
}

if ( Push_button_state2 == HIGH )
{
  Serial.println("button2");
}

if ( Push_button_state3 == HIGH )
{
  Serial.println("button3");
}

if ( Push_button_state4 == HIGH )
{
  Serial.println("button4");
}


digitalWrite(INDICATOR1, HIGH);
digitalWrite(INDICATOR2, HIGH);
delay(200);

digitalWrite(INDICATOR1, LOW);
digitalWrite(INDICATOR2, LOW);


digitalWrite(INDICATOR3, HIGH);
digitalWrite(INDICATOR4, HIGH);
delay(200);

digitalWrite(INDICATOR3, LOW);
digitalWrite(INDICATOR4, LOW);


digitalWrite(INDICATOR5, HIGH);
digitalWrite(INDICATOR6, HIGH);
delay(200);

digitalWrite(INDICATOR5, LOW);
digitalWrite(INDICATOR6, LOW);






}

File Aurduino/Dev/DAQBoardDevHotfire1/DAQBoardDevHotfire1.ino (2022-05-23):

/*
This code runs on the DAQ ESP32 and has a couple of main functions.
1. Read sensor data
2. Send sensor data to COM ESP32
3. Recieve servo commands from COM ESP32
4. Send PWM signals to servos
*/

#include <esp_now.h>
#include <WiFi.h>
#include <ESP32Servo.h>
#include <Wire.h>
#include <Arduino.h>
#include "HX711.h"


#define FMPIN 4 //Flowmeter pin
#define PTDOUT1 32
#define CLKPT1 5
#define PTDOUT2 15
#define CLKPT2 2
#define PTDOUT3 22
#define CLKPT3 23
#define PTDOUT4 19
#define CLKPT4 21
#define PTDOUT5 35
#define CLKPT5 25
#define PTDOUT6 34
#define CLKPT6 26
#define PTDOUT7 39
#define CLKPT7 33

#define SERVOPIN1 13
#define SERVOPIN2 12
#define RELAYPIN1 14
#define RELAYPIN2 27

#define servo1ClosedPosition 100
#define servo1OpenPosition 10
#define servo2ClosedPosition 80
#define servo2OpenPosition 160

float currentPosition1 = float('inf');
float currentPosition2 = float('inf');

//define servo min and max values
#define SERVO_MIN_USEC (800)
#define SERVO_MAX_USEC (2100)
//define servo necessary values
#define ADC_Max 4096;


//PT CALIBRATION CONSTANTS
double PT1C1 =0.0001129;
double PT1C2 =12.49;
double PT2C1 =0.00002772;
double PT2C2 =17.53;
double PT3C1 =.0001438;
double PT3C2 =16.23;
double PT4C1 = 0.00002767;
double PT4C2 =18.94;
double PT5C1 =-.000303;
double PT5C2 =-.154;
double PT6C1 =-0.000341;
double PT6C2 =0.833;
double PT7C1 =-.000250;
double PT7C2 =1.64;

double PTdiv =100;


//Initialize flow meter variables for how it computes the flow amount
short currentMillis = 0;
short goalTime = 50;
short currReading1;
short currReading2;
short loopTime=10;


unsigned long igniteTimeControl = 0;
unsigned long igniteTime =  250;

float servo1curr =0;
float servo2curr=0;

//FM counter
float fmcount;
float flowRate;
boolean currentState;
boolean lastState = false;

// Serial Message setup
String serialMessage = "";

//Measuring output from voltage divider
int readVoltage;
float convertedVoltage;

//Initialize the PT and LC sensor objects which use the HX711 breakout board
HX711 scale1;
HX711 scale2;
HX711 scale3;
HX711 scale4;
HX711 scale5;
HX711 scale6;
HX711 scale7;

//Initialize the servo objects
Servo servo1;
Servo servo2;

///////////////
//IMPORTANT
//////////////
// REPLACE WITH THE MAC Address of your receiver

//OLD COM BOARD {0xC4, 0xDD, 0x57, 0x9E, 0x91, 0x6C}
// COM BOARD {0x7C, 0x9E, 0xBD, 0xD7, 0x2B, 0xE8}
//HEADERLESS BOARD {0x7C, 0x87, 0xCE, 0xF0 0x69, 0xAC}
//NEWEST COM BOARD IN EVA {0x24, 0x62, 0xAB, 0xD2, 0x85, 0xDC}
// uint8_t broadcastAddress[] = {0x24, 0x62, 0xAB, 0xD2, 0x85, 0xDC};
uint8_t broadcastAddress[] ={0x7C, 0x9E, 0xBD, 0xD7, 0x2B, 0xE8};
// {0x7C, 0x87, 0xCE, 0xF0, 0x69, 0xAC};
//{0x3C, 0x61, 0x05, 0x4A, 0xD5, 0xE0};
// {0xC4, 0xDD, 0x57, 0x9E, 0x96, 0x34}

int count=3;

//STATEFLOW VARIABLES
int state=-1;
unsigned int dataArraySize =0;
int loopStartTime=0;
int MeasurementDelay=1000; //Delay between data measurment periods in the idle loop state in m
int idleMeasurementDelay=1000;
int pollingMeasurementDelay=200;
int hotfireMeasurementDelay=2;

int lastPrintTime=0;
int PrintDelay =1000;

int lastMeasurementTime=-1;
short int queueLength=0;
int commandedState;

int hotfireStage1Time=250;
int hotfireStage2Time=2500;
int hotfireStage3Time=2800;
int hotfireStage4Time=3000;
int igniterTime=750;

int hotfireTimer=0;
int igniterTimer=0;



//the following are only used in the oposite direction, they are included because it may be necessary for the structure to be the same in both directions
int S1;
int S2;
// int S1S2;
int I;

// int commandedState;
// int prev_S1S2 = 0;
bool ignite = 1;

// Define variables to store incoming commands, servos and igniter
int incomingS1;
int incomingS2;
// int incomingS1S2;
bool incomingI;

int DAQstate = 0;

// int I = 0;

float startTime;
float endTime;
float timeDiff;

// Variable to store if sending data was successful
String success;

// Define variables to store readings to be sent
int messageTime=10;
short int pt1val=1;
short int pt2val=1;
short int pt3val=1;
short int pt4val=1;
short int pt5val=1;
short int pt6val=1;
short int pt7val=1;
short int fmval=2;


//Structure example to send data
//Must match the receiver structure
typedef struct struct_message {
    int messageTime;
    short int pt1val; short int pt2val; short int pt3val; short int pt4val; short int pt5val; short int pt6val; short int pt7val;
    short int fmval;

    unsigned char S1; unsigned char S2; int commandedState=1; 
    int DAQstate=0;unsigned char I; short int queueSize;
    int Debug;
} struct_message;

// Create a struct_message called Readings to hold sensor readings
struct_message Readings;
//create a queue for readings in case
struct_message ReadingsQueue[120];

// Create a struct_message to hold incoming commands
struct_message Commands;

esp_now_peer_info_t peerInfo;





// Callback when data is sent
void OnDataSent(const uint8_t *mac_addr, esp_now_send_status_t status) {
  Serial.print("\r\nLast Packet Send Status:\t");
   Serial.println(status == ESP_NOW_SEND_SUCCESS ? "Delivery Success" : "Delivery Fail");
   if (status ==0){
     success = "Delivery Success :)";
   }
   else{
     success = "Delivery Fail :(";
   }
}

// Callback when data is received
void OnDataRecv(const uint8_t * mac, const uint8_t *incomingData, int len) {
  memcpy(&Commands, incomingData, sizeof(Commands));
 //  Serial.print("Bytes received: ");
 //  Serial.print(len);
      // digitalWrite(ONBOARD_LED,HIGH);

  S1 =Commands.S1;
  S2 = Commands.S2;
  // Serial.print(Commands.S1);
  // Serial.print(" ");
  // Serial.println(Commands.S2);

 // UNCOMMENT THIS LATER!!!!!!!!!!!!!!!!
 commandedState = Commands.commandedState;
 // Serial.println(commandedState);

}


void SerialRead() {
    if (Serial.available() > 0) {
 commandedState=Serial.read()-48;
 Serial.print("AVAILABLE--------------------");
    Serial.println(commandedState);
    Serial.println(" ");

  }


     //   Serial.println(commandedState);
    //    Serial.println(" ");

}




void setup() {
  //attach servo pins
  servo1.attach(SERVOPIN1,SERVO_MIN_USEC,SERVO_MAX_USEC);
  servo2.attach(SERVOPIN2,SERVO_MIN_USEC,SERVO_MAX_USEC);

  // attach onboard LED
  // pinMode(ONBOARD_LED,OUTPUT);
  pinMode(RELAYPIN1, OUTPUT);
  pinMode(RELAYPIN2, OUTPUT);

  digitalWrite(RELAYPIN1, HIGH);
  digitalWrite(RELAYPIN2, HIGH);

//set gains for pt pins
  scale1.begin(PTDOUT1, CLKPT1); scale1.set_gain(64);
  scale2.begin(PTDOUT2, CLKPT2); scale2.set_gain(64);
  scale3.begin(PTDOUT3, CLKPT3); scale3.set_gain(64);
  scale4.begin(PTDOUT4, CLKPT4); scale4.set_gain(64);
  scale5.begin(PTDOUT5, CLKPT5); scale5.set_gain(64);
  scale6.begin(PTDOUT6, CLKPT6); scale6.set_gain(64);
  scale7.begin(PTDOUT7, CLKPT7); scale7.set_gain(64);
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

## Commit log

2022-04-03 Apr 2 Edition
    First upload to ellie-ground project
2022-04-03 added sending command back to COM Board
2022-04-04 adding sensor board schematic
    [sensor_board.kicad_pcb, sensor_board.kicad_sch]
2022-04-04 Adding layout for sensor board
    [sensor_board.kicad_pcb, sensor_board.kicad_sch]
2022-04-04 Adding schematic for sensor board
    [sensor_board.kicad_pcb, sensor_board.kicad_sch]
2022-04-04 custom board
    [EllieBoard.kicad_pcb, EllieBoard.kicad_sch]
2022-04-05 fixing some issues with schematic
    [EllieBoard.kicad_sch]
2022-04-05 Revert "Add files via upload"
    This reverts commit e99c1198ff01b9ae491ee7c082d96d64acfec7d3.
    [DAQBoard.ino]
2022-04-05 Revert "Revert "Add files via upload""
    This reverts commit 7839cd9de83ff867efd8fdbad404a527c5cbbfa3.
    [DAQBoard.ino]
2022-04-05 FM Calibration Code
    Created flowmeter calibration code and fixed existing flowmeter code in DAQ
    [DAQBoard.ino]
2022-04-05 Updated code 1 AM 4/5
    Finalized FM calibration code and DAQ code
2022-04-05 updated board electronics work session 04/04
    [EllieBoard.kicad_sch]
2022-04-05 updated schematic electronics work session 04/05
2022-04-05 kicad board work
    custom board updates
    [EllieBoard.kicad_pcb, EllieBoard.kicad_sch]
2022-04-05 Update on ESP32 reference materials
2022-04-05 some updates to layout, not 100% done yet
    [EllieBoard.kicad_pcb]
2022-04-05 Updated layout for review
    [EllieBoard.kicad_pcb]
2022-04-05 Updated layout for board, added silkscreen
    [EllieBoard.kicad_pcb]
2022-04-06 flow meter calibration changes before testing
2022-04-06 fm calibration during testing
2022-04-06 Layout updates 04/05
    [EllieBoard.kicad_pcb, EllieBoard.kicad_sch]
2022-04-06 start of flow testing
2022-04-06 Layout changes 04/05
    [EllieBoard.kicad_pcb]
2022-04-06 adding power pours + other misc edits
2022-04-06 matlab code push for hubetr
    [2022-04-05_223852_fm_test1.xls, 2022-04-05_231216_fm_test1.xls]
2022-04-06 mid fm calibration
    [2022-04-05_231637_fm_test1.xls]
2022-04-06 flow meter
    [2022-04-05_231926_fm_test1.xls, 2022-04-05_232006_fm_test1.xls, 2022-04-05_232019_fm_test1.xls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]
2022-04-06 practice data sets
    [2022-04-05_231216_fm_test1.xls, 2022-04-05_231637_fm_test1.xls, 2022-04-05_231926_fm_test1.xls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]
2022-04-06 data from fm calibration
    [2022-04-05_223852_fm_test1.xls, 2022-04-05_230353_fm_test1.xls, 2022-04-05_230529_fm_test1.xls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]
2022-04-06 Fixed power pour, added more silkscreen labels, attempted to make board less massive
    [EllieBoard-B_Cu.gbr, EllieBoard-B_Mask.gbr, EllieBoard-B_Paste.gbr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]
2022-04-06 last few edits to layout
    [EllieBoard-B_Cu.gbr, EllieBoard-B_Mask.gbr, EllieBoard-B_Paste.gbr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]
2022-04-06 matlab plotting code
    [2022-04-06_031539_test3.xls, 2022-04-06_031603_test3.xls, 2022-04-06_031707_test3.xls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]
2022-04-06 adding vias fixing solder mask
    [EllieBoard.kicad_pcb]
2022-04-06 fixing net issues
    [EllieBoard.kicad_pcb]
2022-04-06 PCB Added silkscreen and final review from Trevor
    [EllieBoard.kicad_pcb, HOPE_template.kicad_pcb, HOPE_template.kicad_sch]
2022-04-06 Kicad board connector and silkscreen fixes
    [EllieBoard.kicad_pcb, EllieBoard.kicad_sch]
2022-04-07 Working DAQ & COM Board before GOX testing
2022-04-07 gox flow testing data
2022-04-09 gox flow testing matlab code
2022-04-10 dev version of com board
2022-04-10 daq board to dev
2022-04-11 small dev board changes
2022-04-11 Revert "tt"
    This reverts commit 54d455385d4b6d7aa855cfb8e0c930104250ae1c.
    [2022-04-10_175802_test3.xls, 2022-04-10_175816_test3.xls, 2022-04-10_175827_test3.xls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]
2022-04-12 Fixed issues with live plot
    2 issues fixed:
    1. COM unable to interface with liveplot (set up functions to catch no reading case)
    2. change the fscaf() timeout time, so the program will only take between 0.75 (with reading no timeout) to 2 (without reading timeout) seconds to get ready
    [COMBoard.ino]
2022-04-12 COM board code LED update
    Now LED can display the states. Problem with shutting off matlab code modifies state to 0 remains. the issue is that MATLAB fclose, clear, instrreset functions would reset the esp32, therefore resetting the state variable to 0
    [2022-04-11_233911_test3.xls, 2022-04-11_233931_test3.xls]
2022-04-13 PT color code
    [2022-04-12_101900_test3.xls]
2022-04-13 Revert "Merge branch 'main' of https://github.com/calstar/ellie-ground"
    This reverts commit 19382aaf51256c20d619034d2db27a935fc07c62, reversing
    changes made to 4dbdb6cad9a543b6ff85faa7afed69d0076f4346.
    [2022-04-12_101900_test3.xls]
2022-04-13 Enabled LEDs
    LEDs
2022-04-13 Revert "Merge branch 'main' of https://github.com/calstar/ellie-ground"
    This reverts commit fc31e91a51d2958665cf79de26ba3b0561605e51, reversing
    changes made to fb18d1940c5d94178e9e6579c36cea799c117d0d.
    [COMBoard.ino, DAQBoard.ino]
2022-04-13 Revert "Revert "Merge branch 'main' of https://github.com/calstar/ellie-ground""
    This reverts commit ee03be48f70488f3a0436184d735dd6d9fed3472.
    [COMBoard.ino, DAQBoard.ino]
2022-04-15 com input board testing code
2022-04-16 Final code changes
    [2022-04-15_233915_test3.xls, 2022-04-15_234147_test3.xls, 2022-04-15_234159_test3.xls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]
2022-04-16 Fix for dead zone
    [COMBoard.ino, DAQBoard.ino]
2022-04-25 Left over commit
    [2022-04-16_162139_test3.xls]
2022-04-25 Resting power draw fix
    [DAQBoard.ino]
2022-04-25 Reduce igniter power draw
2022-04-28 added code to measure voltage
2022-05-01 (test) measure from voltage divider
    [EllieBoard.kicad_pcb]
2022-05-13 may12work session
    [2022-04-05_223852_fm_test1.xls, 2022-04-05_230353_fm_test1.xls, 2022-04-05_230529_fm_test1.xls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]
2022-05-13 update may12 last
    [load_cell_calibration_1.xls]
2022-05-14 Changed load cell to PT
    [load_cell_calibration_1.xls]
2022-05-17 may 16 daq plus other updates
    [2022-05-16_183212_test3.xls, 2022-05-16_183234_test3.xls, 2022-05-16_183320_test3.xls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]
2022-05-17 voltage sensing code
2022-05-17 updated relay test
2022-05-18 labview com board start
2022-05-19 Main Update
    [2022-05-18_191245_test3.xls, 2022-05-18_191444_test3.xls, 2022-05-18_191811_test3.xls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]
2022-05-19 random matlab stuff
    [2022-05-18_191245_test3.xls, 2022-05-18_191444_test3.xls, 2022-05-18_191811_test3.xls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]
2022-05-19 moved daq board dev to different folder
2022-05-20 Redone COM DEV board
2022-05-23 FAR Hotfire changes and MATAB data analysis
    [HotfireData.xlsx, HotfireData2.xlsx]
2022-06-02 Processed Hot Fire Data
    [HotfireData2_Processed.xls, HotfireData_Processed.xls]
2022-06-15 DataAnalysis update
    [HotfireData2_Processed.xls]
2022-06-28 Mass flow meter
2022-06-28 Change file path
    [EllieBoard-B_Cu.gbr, EllieBoard-B_Mask.gbr, EllieBoard-B_Paste.gbr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]
2022-08-25 added kicad files
    [EllieBoard-B_Cu.gbr, EllieBoard-B_Mask.gbr, EllieBoard-B_Paste.gbr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]
2022-08-26 new pcb
    [EllieBoard.kicad_pcb, le2_ground.kicad_pcb, le2_ground.kicad_sch]
2022-09-03 Sensor Code Ready For Calibration
2022-09-17 Matlab update
    [PTCalibration_1.xls]
2022-09-24 Update on CD calculation
    [Sep102022CdCalcr2.xls, Sep102022CdCalcr3.xls, Sep102022CdCalcr4.xls]
2022-09-25 Sep24 builday final
    [Sep102022CdCalcr.xls, Sep102022CdCalcr1.xls, Sep102022CdCalcr2.xls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]
2022-09-25 Deletion of files
    [Sep102022CdCalcr1.xls]
2022-09-25 Rename folders
    [EllieBoard-B_Cu.gbr, EllieBoard-B_Mask.gbr, EllieBoard-B_Paste.gbr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]
2022-10-04 flow Meter fixed
    [OCt32022CdCalcr1.xls, OCt32022CdCalcr2.xls, OCt32022CdCalcr3.xls]
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2022-11-02 test
    test
    [OCt072022CdCalcr3.xls, OCt082022CdCalcr3.xls, OCt502022CdCalcr3.xls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]
2023-04-10 revert to original hotfire
    [DAQBoard.ino]
